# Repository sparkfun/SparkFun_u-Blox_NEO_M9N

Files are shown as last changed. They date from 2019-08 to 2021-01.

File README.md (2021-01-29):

SparkFun GPS NEO-M9N Breakout (Chip Antenna, U.FL, SMA) 
========================================

<table class="table table-hover table-striped table-bordered">
  <tr align="center">
   <td></td>
   <td></td>
    <td></td>
  </tr>
  <tr align="center">
    <td><a href="https://www.sparkfun.com/products/15733">SparkFun GPS NEO-M9N Chip Antenna <br />(GPS-15733)</a></td>
    <td><a href="https://www.sparkfun.com/products/15712">SparkFun GPS NEO-M9N U.FL <br />(GPS-15172)</a></td>
    <td><a href="https://www.sparkfun.com/products/17285">SparkFun GPS NEO-M9N SMA <br />(GPS-17285)</a></td>
  </tr>
</table>

The SparkFun NEO-M9N GPS Breakout is a high quality, GPS board with equally impressive configuration options. The NEO-M9N module is a 92-channel u-blox M9 engine GNSS receiver, meaning it can receive signals from the GPS, GLONASS, Galileo, and BeiDou constellations with ~1.5 meter accuracy. This breakout supports concurrent reception of four GNSS maximizes position accuracy in challenging conditions increasing precision and decreases lock time and thanks to the onboard rechargeable battery, you'll have backup power enabling the GPS to get a hot lock within seconds! Additionally, this u-blox receiver supports I<sup>2</sup>C (u-blox calls this Display Data Channel) which made it perfect for the Qwiic compatibility so we don't have to use up our precious UART ports. Utilizing our handy Qwiic system, no soldering is required to connect it to the rest of your system. However, we still have broken out 0.1"-spaced pins in case you prefer to use a breadboard. 

The NEO-M9N module detects jamming and spoofing events and can reports them to the host, so that the system can react to such events. A SAW (Surface Acoustic Wave) filter combined with an LNA (Low Noise Amplifier) in the RF path is integrated into the NEO-M9N module which allows normal operation even under strong RF interferences.

U-blox based GPS products are configurable using the popular, but dense, windows program called u-center. Plenty of different functions can be configured on the NEO-M9N: baud rates, update rates, geofencing, spoofing detection, external interrupts, SBAS/D-GPS, etc. All of this can be done within the SparkFun Arduino Library!

The SparkFun NEO-M9N GPS Breakout is also equipped with an on-board rechargeable battery that provides power to the RTC on the NEO-M9N.  This reduces the time-to-first fix from a cold start (~24s) to a hot start (~2s). The battery will maintain RTC and GNSS orbit data without being connected to power for plenty of time. 

Repository Contents
-------------------

* **/Documentation** - Data sheets for the NEO-M9N
* **/Hardware** - Eagle design files (.brd, .sch)
* **/Production** - Production panel files (.brd)

Documentation
--------------
* **[Library](https://github.com/sparkfun/SparkFun_u-blox_GNSS_Arduino_Library)** - Arduino Library the SparkFun GPS NEO-M9N.
* **[Qwiic UBlox GPS Py](https://github.com/sparkfun/Qwiic_Ublox_Gps_Py)** - Python Package
* **[Hookup Guide](https://learn.sparkfun.com/tutorials/sparkfun-gps-neo-m9n-hookup-guide)** - Basic hookup guide for the SparkFun GPS NEO-M9N

Product Versions
----------------
* [GPS-17285](https://www.sparkfun.com/products/17285) - GPS NEO-M9N SMA
* [GPS-15733](https://www.sparkfun.com/products/15733) - GPS NEO-M9N Chip Antenna
* [GPS-15712](https://www.sparkfun.com/products/15712) - GPS NEO-M9N u.FL

License Information
-------------------

This product is _**open source**_! 

Please review the LICENSE.md file for license information. 

If you have any questions or concerns on licensing, please contact technical support on our [SparkFun forums](https://forum.sparkfun.com/viewforum.php?f=152).

Distributed as-is; no warranty is given.

- Your friends at SparkFun.

_<COLLABORATION CREDIT>_

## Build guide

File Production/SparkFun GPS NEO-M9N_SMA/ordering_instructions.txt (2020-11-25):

panel size, 154x93mm
PCB thickness, 1.6mm
number of layers, 2
soldermask color, Red
silkscreen color, White
oz copper, 1oz
finish, HASL lead free
stencils, none
pcs per panel, 6
min trace width, 0.1524mm / 0.0060in
min drill size, 0.3048mm / 0.0120in

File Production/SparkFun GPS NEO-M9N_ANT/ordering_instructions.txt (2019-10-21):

panel size, 96x160mm
PCB thickness, 1.6mm
number of layers, 2
soldermask color, Red
silkscreen color, White
oz copper, 1oz
finish, HASL lead free
stencils, top+bottom
pcs per panel, 8
min trace width, 0.152400mm / 0.006000in
min drill size, 0.304800mm / 0.012000in

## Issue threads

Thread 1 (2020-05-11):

DFM issue with production PCB

szechyjs, 2020-05-11:
GTP is different than solder mask layer and the opening on the paste layer will cause the trace layer copper exposure.

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

edspark, 2020-05-11:
You're right about the classification of the layers but I think there's a little confusion on what they do. As you mentioned the GTP is "Gerber Top Paste" and is *not* the solder stop mask layer. Solder stop as you may know, stops the mask that covers and protects the copper. The solder stop mask layer in your image is the dark pink and the light-ish pink turned into green is the **top-paste**. It is usually the case that the paste fits inside the **solder stop** because solder only adheres to exposed copper (obviously). So, looking at the image linked in your comment, I can see that the **stop layer**, stops where the traces exits the pad. So no problem there.

The GTP in production is used entirely for the stencils that apply paste. What you're seeing is *not* exposed copper but "over-pasting". We use this technique on most of  the modules in our catalog that have castellated leads. If you've seen them then you know what I'm talking about. Just in case you haven't, those castellated leads have a lot of extra metal on them that suck up a lot of solder, and so we use this technique so that we get enough paste for good solder flow all the way up the lead.

In case you're not convinced, you can check the images we have on our [product page](https://www.sparkfun.com/products/16329), and see that the copper is *not* exposed at places where you might expect them to be. Or you can drag and drop the gerber files in this repository into this [3d Gerber Viewer](http://mayhewlabs.com/3dpcb) and get really up close to see what I'm talking about.

Closed 2020-05-11.

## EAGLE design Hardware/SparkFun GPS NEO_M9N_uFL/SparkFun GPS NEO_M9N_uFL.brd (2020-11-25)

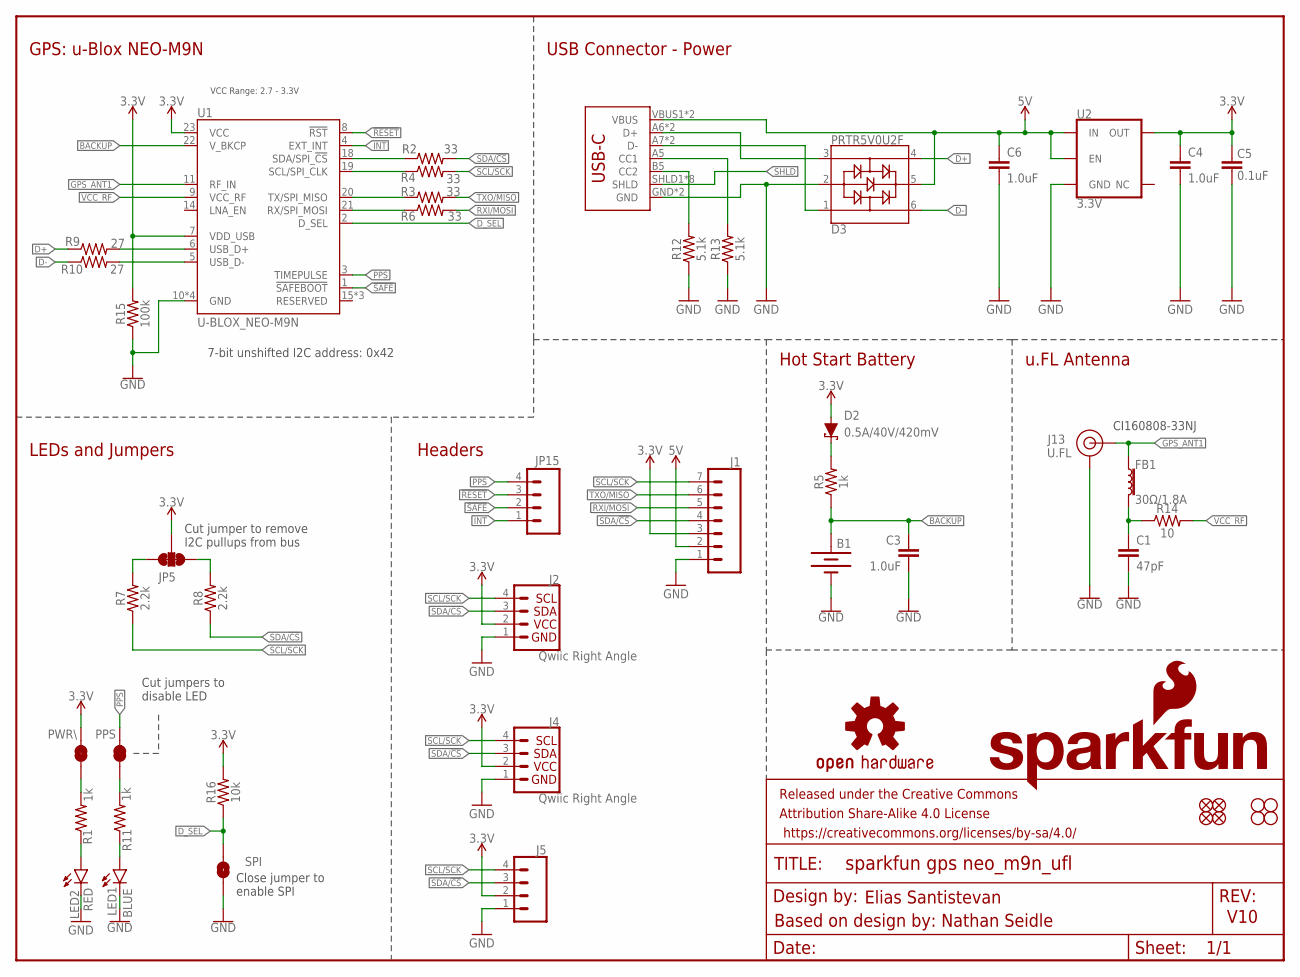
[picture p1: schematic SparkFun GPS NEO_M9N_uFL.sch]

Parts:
B1: 6.8MM_COIN_CELL; ML414H_IV01E
C1: 47pF; 0603
C3, C4, C6: 1.0uF; 0603
C5: 0.1uF; 0603
D2: 0.5A/40V/420mV; SOD-323
D3: PRTR5V0U2F; SOT886
FB1: 30Ω/1.8A; 0603
FRAME1: FRAME-LETTER; CREATIVE_COMMONS
J1: CONN_07NO_SILK; 1X07_NO_SILK
J2, J4: Qwiic Right Angle; JST04_1MM_RA
J3: USB_C2-LAYER; USB-C-16P
J5: CONN_041X04_NO_SILK; 1X04_NO_SILK
J13: U.FL
JP5: JUMPER-SMT_3_2-NC_TRACE_SILK; SMT-JUMPER_3_2-NC_TRACE_SILK
JP15: CONN_041X04_NO_SILK; 1X04_NO_SILK
JP21, JP61, JP71, JP81: FIDUCIALUFIDUCIAL; MICRO-FIDUCIAL
JP31, JP41, JP91, JP101: STAND-OFF
LED1: BLUE; LED-0603
LED2: RED; LED-0603
LOGO1: OSHW-LOGOMINI; OSHW-LOGO-MINI
LOGO2: SFE_LOGO_NAME_FLAME.1_INCH; SFE_LOGO_NAME_FLAME_.1
PPS: JUMPER-SMT_2_NC_TRACE_SILK; SMT-JUMPER_2_NC_TRACE_SILK
PWR\: JUMPER-SMT_2_NC_TRACE_SILK; SMT-JUMPER_2_NC_TRACE_SILK
R1, R5, R11: 1k; 0603
R2, R3, R4, R6: 33; 0603
R7, R8: 2.2k; 0603
R9, R10: 27; 0603
R12, R13: 5.1k; 0603
R14: 10; 0603
R15: 100k; 0603
R16: 10k; 0402
SPI: JUMPER-SMT_2_NO_SILK; SMT-JUMPER_2_NO_SILK
U1: U-BLOX_NEO-M9N; NEO-M9N
U2: 3.3V; SOT23-5

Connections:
3.3V: C4.1, C5.2, D2.A, J1.3, J2.2, J4.2, J5.2, JP5.2, PWR\.2, R15.2, R16.2, U1.7 (VDD_USB), U1.23 (VCC), U2.5 (OUT)
5V: C6.1, D3.5, J1.2, J3.VBUS1 (VBUS), J3.VBUS2 (VBUS), U2.1 (IN), U2.3 (EN)
!RESET: JP15.3, U1.8 (!RST)
!SAFE: JP15.2, U1.1 (!SAFEBOOT!)
ANT_VCC: C1.1, FB1.2, R14.1
BACKUP: B1.+, C3.1, R5.1, U1.22 (V_BKCP)
D+: D3.4, R9.1
D-: D3.6, R10.1
D_SEL: R16.1, SPI.2, U1.2 (D_SEL)
GND: B1.-, C1.2, C3.2, C4.2, C5.1, C6.2, D3.2, J1.1, J2.1, J3.GND, J3.GND2 (GND), J4.1, J5.1, J13.1 (GND), J13.2 (GND), LED1.C, LED2.C, R12.1, R13.1, R15.1, SPI.1, U1.10 (GND), U1.12 (GND), U1.13 (GND), U1.24 (GND), U2.2 (GND)
GPS_ANT1: FB1.1, J13.FEED (SIGNAL), U1.11 (RF_IN)
INT: JP15.1, U1.4 (EXT_INT)
unnamed: PWR\.1, R1.2
unnamed: LED1.A, R11.1
unnamed: PPS.1, R11.2
unnamed: JP5.1, R8.2
unnamed: D2.C, R5.2
unnamed: J3.B5 (CC2), R12.2
unnamed: JP5.3, R7.2
unnamed: J3.A5 (CC1), R13.2
unnamed: LED2.A, R1.1
unnamed: R9.2, U1.6 (USB_D+)
unnamed: R10.2, U1.5 (USB_D-)
PPS: JP15.4, PPS.2, U1.3 (TIMEPULSE)
RXI/MOSI: J1.5, R6.2
RXLV: R6.1, U1.21 (RX/SPI_MOSI)
SCL/SCK: J1.7, J2.4, J4.4, J5.4, R4.2, R7.1
SCL_LV: R4.1, U1.19 (SCL/SPI_CLK)
SDA/!CS: J1.4, J2.3, J4.3, J5.3, R2.2, R8.1
SDA_LV: R2.1, U1.18 (SDA/SPI_!CS!)
SHLD: J3.SHLD1 (SHLD), J3.SHLD2 (SHLD), J3.SHLD3 (SHLD), J3.SHLD4 (SHLD), J3.SHLD5 (SHLD), J3.SHLD6 (SHLD), J3.SHLD7 (SHLD), J3.SHLD8 (SHLD)
TXLV: R3.1, U1.20 (TX/SPI_MISO)
TXO/MISO: J1.6, R3.2
USB_D+: D3.3, J3.A6 (D+), J3.B6 (D+)
USB_D-: D3.1, J3.A7 (D-), J3.B7 (D-)
VCC_RF: R14.2, U1.9 (VCC_RF)

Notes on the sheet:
V10
7-bit unshifted I2C address: 0x42
Cut jumper to remove I2C pullups from bus
Cut jumpers to disable LED
Close jumper to enable SPI
CI160808-33NJ
Elias Santistevan
Headers
LEDs and Jumpers
Hot Start Battery
GPS: u-Blox NEO-M9N
u.FL Antenna
USB Connector - Power
Based on design by: Nathan Seidle
VCC Range: 2.7 - 3.3V

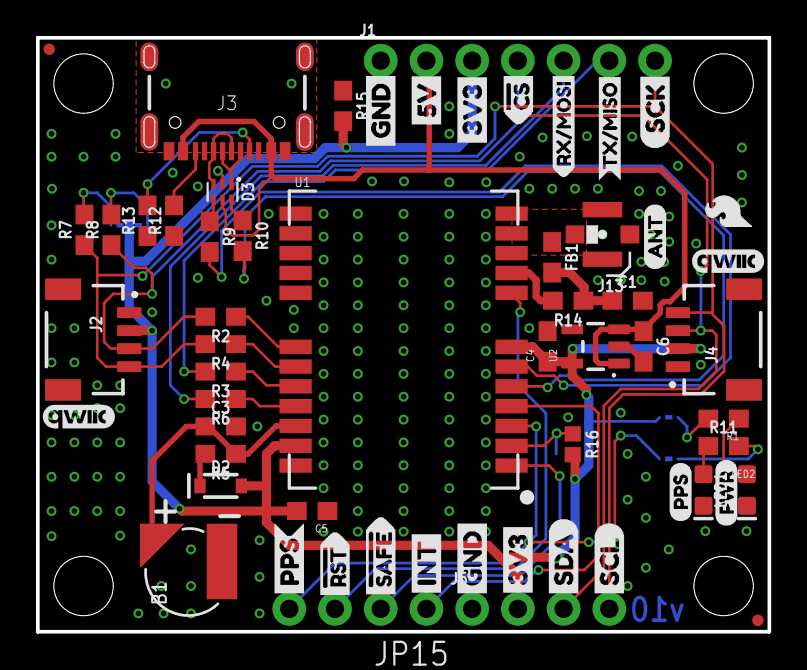
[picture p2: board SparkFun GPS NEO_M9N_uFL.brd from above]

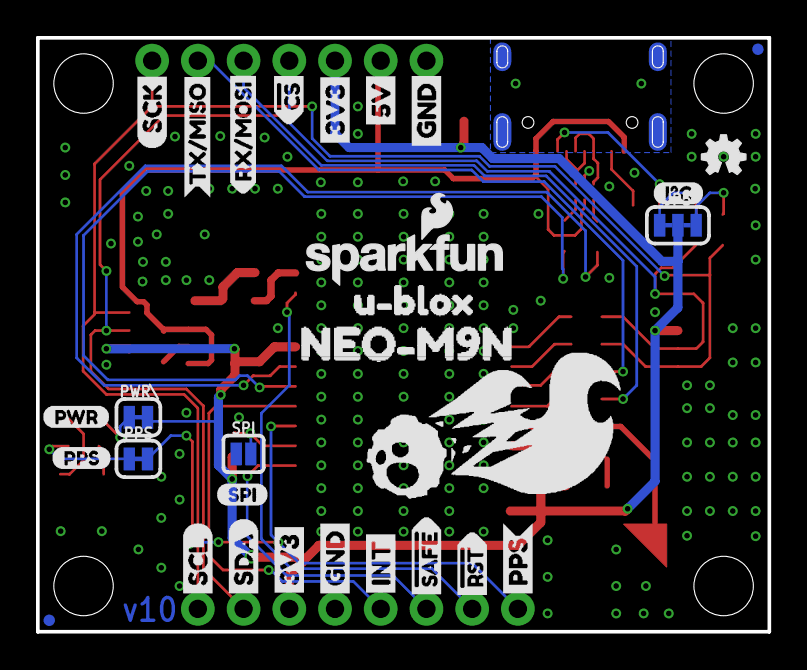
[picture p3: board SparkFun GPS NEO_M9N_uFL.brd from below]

Board: 2 copper layers, 40.6 x 33.0 mm, 94 parts (30 on the bottom side), 36 nets.

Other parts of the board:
U$1, U$4: SDA-[)
U$2: NEO#M9N1
U$3, U$5: SCL-[)
U$6, U$7, U$60, U$61: 3V3-04
U$8, U$9, U$62, U$63: GND-04
U$10: I_SUPER2_C-()-03
U$11: SPI1
U$12, U$52: PPS0
U$13, U$14: QWIIC_4MM
U$15, U$16: INT8
U$17: PWR1
U$18: PWR-()-03
U$19, U$20: 5V
U$21: NEO_GPS_BOARD_SILK_FINAL#03#JPG
U$22: U#BLOX3
U$23, U$24: CS#-<]
U$25: ANT0
U$26: RX#MOSI2
U$31: RX#MOSI3
U$33: SFE_LOGO_FLAME_.1
U$34: TX#MISO0
U$35, U$36: #RST3
U$37: TX#MISO1
U$38, U$41: SCK-(]-04
U$39, U$40: #SAFE1
U$43, U$44: PPS5

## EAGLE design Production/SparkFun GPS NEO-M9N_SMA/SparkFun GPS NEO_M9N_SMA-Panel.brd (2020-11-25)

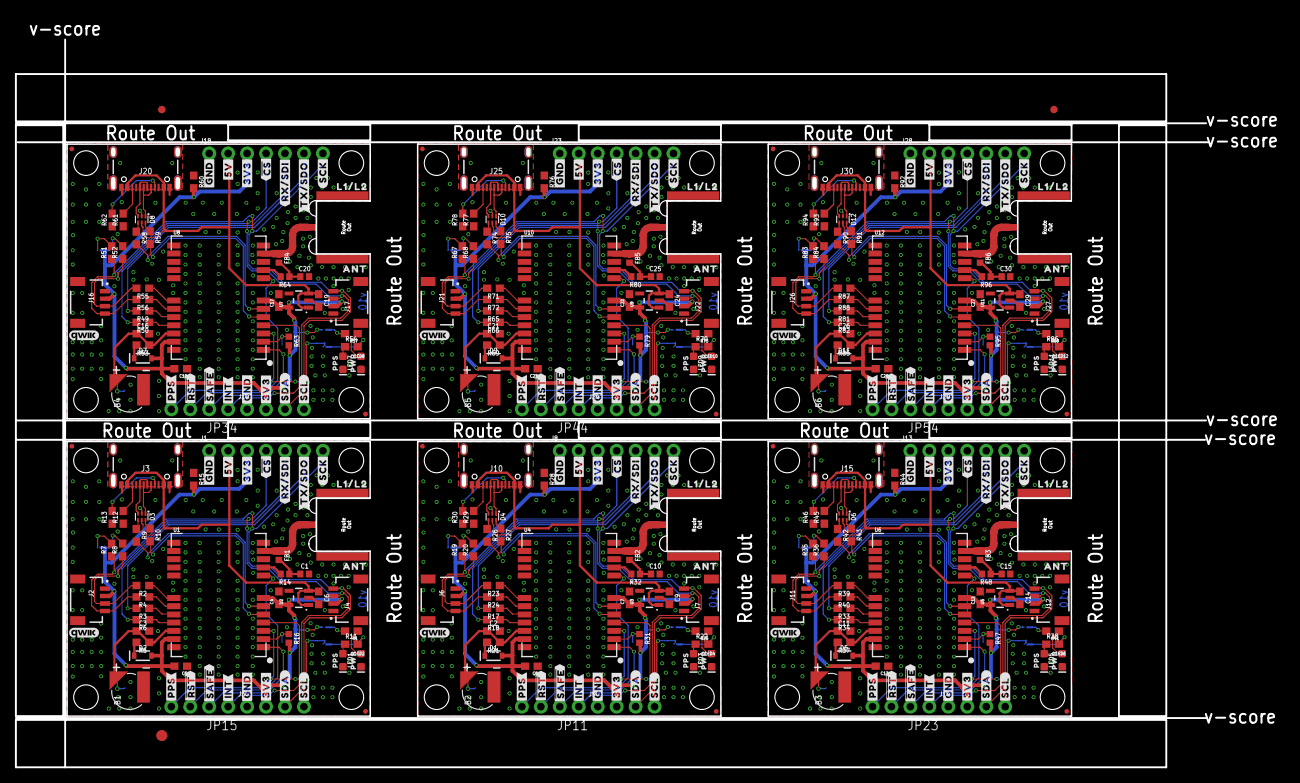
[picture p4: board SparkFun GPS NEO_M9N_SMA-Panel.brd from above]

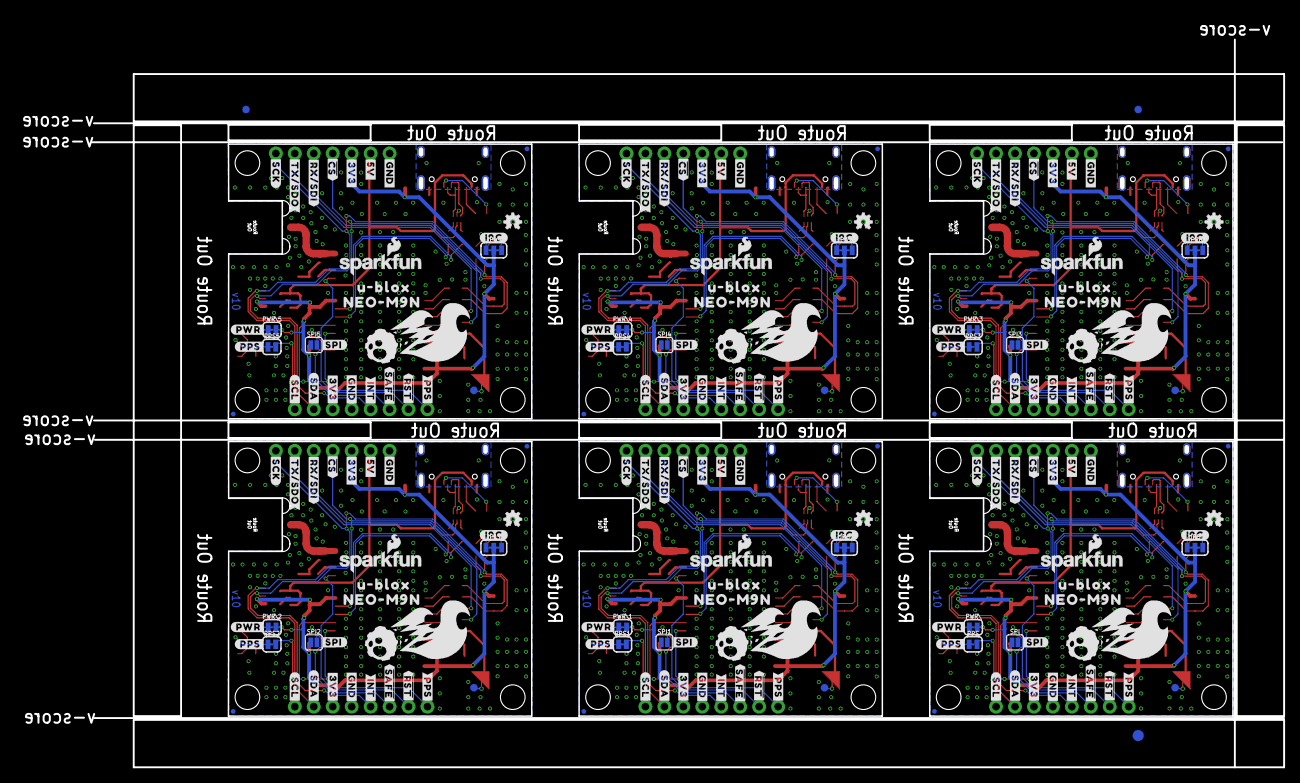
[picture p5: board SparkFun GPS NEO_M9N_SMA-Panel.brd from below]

Board: 2 copper layers, 159.8 x 97.5 mm, 564 parts (189 on the bottom side), 216 nets.

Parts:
B1, B2, B3, B4, B5, B6: 6.8MM_COIN_CELL; ML414H_IV01E
C1, C10, C15, C20, C25, C30: 47pF; 0402
C2, C3, C4, C6, C7, C9, C11, C12, C14, C16, C17, C19, C21, C22, C24, C26, C27, C29: 1.0uF; 0603
C5, C8, C13, C18, C23, C28: 0.1uF; 0603
D1, D2, D5, D7, D9, D11: 0.5A/40V/420mV; SOD-323
D3, D4, D6, D8, D10, D12: PRTR5V0U2F; SOT886
E1, E2, E3, E4, E5, E6: ANTENNA-GROUNDEDEDGE_SMA_SMD; SMA-EDGE-SMD
E$1, E$2, E$3, E$4: FIDUCIAL-1X2
E$5, E$6: FIDUCIAL-1.5X3
FB1, FB2, FB3, FB4, FB5, FB6: FERRITE_BEAD-120_OHM-0402; 0402
J1, J8, J13, J18, J23, J28: 1X07_NO_SILK
J2, J4, J6, J7, J11, J12, J16, J17, J21, J22, J26, J27: Qwiic Right Angle; JST04_1MM_RA
J3, J10, J15, J20, J25, J30: USB-C-16P-2LAYER-PADS
J5, J9, J14, J19, J24, J29: 1X04_NO_SILK
JP1, JP2, JP9, JP10, JP12, JP13, JP20, JP22, JP24, JP25, JP31, JP32, JP33, JP35, JP36, JP42, JP43, JP45, JP46, JP52, JP53, JP55, JP91, JP101: STAND-OFF
JP3, JP4, JP7, JP8, JP14, JP16, JP18, JP19, JP21, JP26, JP27, JP29, JP30, JP37, JP38, JP40, JP41, JP47, JP48, JP50, JP51, JP61, JP71, JP81: FIDUCIALUFIDUCIAL; MICRO-FIDUCIAL
JP5, JP6, JP17, JP28, JP39, JP49: JUMPER-SMT_3_2-NC_TRACE_SILK; SMT-JUMPER_3_2-NC_TRACE_SILK
JP11, JP15, JP23, JP34, JP44, JP54: 1X04_NO_SILK
LED1, LED3, LED5, LED7, LED9, LED11: BLUE; LED-0603
LED2, LED4, LED6, LED8, LED10, LED12: RED; LED-0603
LOGO1, LOGO3, LOGO5, LOGO7, LOGO9, LOGO11: OSHW-LOGOMINI; OSHW-LOGO-MINI
LOGO2, LOGO4, LOGO6, LOGO8, LOGO10, LOGO12: SFE_LOGO_NAME_FLAME.1_INCH; SFE_LOGO_NAME_FLAME_.1
PPS, PPS1, PPS2, PPS3, PPS4, PPS5: JUMPER-SMT_2_NC_TRACE_SILK; SMT-JUMPER_2_NC_TRACE_SILK
PWR\, PWR\1, PWR\2, PWR\3, PWR\4, PWR\5: JUMPER-SMT_2_NC_TRACE_SILK; SMT-JUMPER_2_NC_TRACE_SILK
R1, R5, R11, R21, R22, R25, R37, R38, R41, R53, R54, R57, R69, R70, R73, R85, R86, R89: 1k; 0603
R2, R3, R4, R6, R17, R18, R23, R24, R33, R34, R39, R40, R49, R50, R55, R56, R65, R66, R71, R72, R81, R82, R87, R88: 33; 0603
R7, R8, R19, R20, R35, R36, R51, R52, R67, R68, R83, R84: 2.2k; 0603
R9, R10, R26, R27, R42, R43, R58, R59, R74, R75, R90, R91: 27; 0603
R12, R13, R29, R30, R45, R46, R61, R62, R77, R78, R93, R94: 5.1k; 0603
R14, R32, R48, R64, R80, R96: 33; 0402
R15, R28, R44, R60, R76, R92: 100k; 0603
R16, R31, R47, R63, R79, R95: 10k; 0402
SPI, SPI1, SPI2, SPI3, SPI4, SPI5: JUMPER-SMT_2_NO_SILK; SMT-JUMPER_2_NO_SILK
TP1, TP2, TP3, TP4, TP5, TP6: TEST-POINT3X4; PAD.03X.04
U1, U4, U6, U8, U10, U12: U-BLOX_NEO-M9N; NEO-M9N/M8T/M8U
U2, U3, U5, U7, U9, U11: 3.3V; SOT23-5
U$1, U$45, U$87, U$129, U$171, U$213: ##CS##9
U$2, U$62, U$104, U$146, U$188, U$230: U#BLOX19
U$3, U$46, U$88, U$130, U$172, U$214: ##SAFE##15
U$4, U$5, U$39, U$40, U$47, U$48, U$78, U$79, U$89, U$90, U$120, U$121, U$131, U$132, U$162, U$163, U$173, U$174, U$204, U$205, U$215, U$216, U$246, U$247: #3V3#6
U$6, U$42, U$49, U$81, U$91, U$123, U$133, U$165, U$175, U$207, U$217, U$249: #5V#1
U$7, U$8, U$38, U$41, U$50, U$51, U$77, U$80, U$92, U$93, U$119, U$122, U$134, U$135, U$161, U$164, U$176, U$177, U$203, U$206, U$218, U$219, U$245, U$248: #GND#0
U$9, U$52, U$94, U$136, U$178, U$220: #INT#16
U$10, U$83, U$125, U$167, U$209, U$251: PPS7
U$11, U$32, U$53, U$71, U$95, U$113, U$137, U$155, U$179, U$197, U$221, U$239: #PPS#13
U$12, U$63, U$105, U$147, U$189, U$231: #SPI#22
U$13, U$84, U$126, U$168, U$210, U$252: PWR6
U$14, U$43, U$85, U$127, U$169, U$211: QWIIC_4MM
U$15, U$54, U$96, U$138, U$180, U$222: #RX#SDI#10
U$16, U$55, U$97, U$139, U$181, U$223: #SCK#12
U$17, U$72, U$114, U$156, U$198, U$240: #PWR#1
U$18, U$56, U$98, U$140, U$182, U$224: #SCL#18
U$19, U$57, U$99, U$141, U$183, U$225: #SDA#17
U$20, U$58, U$100, U$142, U$184, U$226: #TX#SDO#11
U$21, U$44, U$86, U$128, U$170, U$212: NEO_GPS_BOARD_SILK_FINAL#03#JPG
U$22, U$67, U$109, U$151, U$193, U$235: ##SAFE##11
U$23, U$59, U$101, U$143, U$185, U$227: L1#L28
U$24, U$60, U$102, U$144, U$186, U$228: ANT8
U$25, U$61, U$103, U$145, U$187, U$229: NEO#M9N20
U$26, U$64, U$106, U$148, U$190, U$232: ##CS##6
U$27, U$65, U$107, U$149, U$191, U$233: ##RST##12
U$28, U$66, U$108, U$150, U$192, U$234: ##RST##2
U$29, U$68, U$110, U$152, U$194, U$236: #I2C#3
U$30, U$69, U$111, U$153, U$195, U$237: #INT#10
U$31, U$70, U$112, U$154, U$196, U$238: #PPS#0
U$33, U$73, U$115, U$157, U$199, U$241: #RX#SDI#4
U$34, U$74, U$116, U$158, U$200, U$242: #SCK#3
U$35, U$75, U$117, U$159, U$201, U$243: #SCL#8
U$36, U$76, U$118, U$160, U$202, U$244: #SDA#9
U$37, U$82, U$124, U$166, U$208, U$250: #TX#SDO#5

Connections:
3.3V: C4.1, C5.2, D2.A, J1.3, J2.2, J4.2, J5.2, JP5.2, PWR\.2, R15.2, R16.2, U1.7, U1.23, U2.5
3.3V1: C7.1, C8.2, D1.A, J6.2, J7.2, J8.3, J9.2, JP6.2, PWR\1.2, R28.2, R31.2, U3.5, U4.7, U4.23
3.3V2: C12.1, C13.2, D5.A, J11.2, J12.2, J13.3, J14.2, JP17.2, PWR\2.2, R44.2, R47.2, U5.5, U6.7, U6.23
3.3V3: C17.1, C18.2, D7.A, J16.2, J17.2, J18.3, J19.2, JP28.2, PWR\3.2, R60.2, R63.2, U7.5, U8.7, U8.23
3.3V4: C22.1, C23.2, D9.A, J21.2, J22.2, J23.3, J24.2, JP39.2, PWR\4.2, R76.2, R79.2, U9.5, U10.7, U10.23
3.3V5: C27.1, C28.2, D11.A, J26.2, J27.2, J28.3, J29.2, JP49.2, PWR\5.2, R92.2, R95.2, U11.5, U12.7, U12.23
5V: C6.1, D3.5, J1.2, J3.VBUS1, J3.VBUS2, U2.1, U2.3
5V1: C9.1, D4.5, J8.2, J10.VBUS1, J10.VBUS2, U3.1, U3.3
5V2: C14.1, D6.5, J13.2, J15.VBUS1, J15.VBUS2, U5.1, U5.3
5V3: C19.1, D8.5, J18.2, J20.VBUS1, J20.VBUS2, U7.1, U7.3
5V4: C24.1, D10.5, J23.2, J25.VBUS1, J25.VBUS2, U9.1, U9.3
5V5: C29.1, D12.5, J28.2, J30.VBUS1, J30.VBUS2, U11.1, U11.3
!RESET: JP15.3, U1.8
!RESET1: JP11.3, U4.8
!RESET2: JP23.3, U6.8
!RESET3: JP34.3, U8.8
!RESET4: JP44.3, U10.8
!RESET5: JP54.3, U12.8
!SAFE: JP15.2, U1.1
!SAFE1: JP11.2, U4.1
!SAFE2: JP23.2, U6.1
!SAFE3: JP34.2, U8.1
!SAFE4: JP44.2, U10.1
!SAFE5: JP54.2, U12.1
D+: D3.4, R9.1
D+1: D4.4, R26.1
D+2: D6.4, R42.1
D+3: D8.4, R58.1
D+4: D10.4, R74.1
D+5: D12.4, R90.1
D-: D3.6, R10.1
D-1: D4.6, R27.1
D-2: D6.6, R43.1
D-3: D8.6, R59.1
D-4: D10.6, R75.1
D-5: D12.6, R91.1
D_SEL: R16.1, SPI.2, U1.2
D_SEL1: R31.1, SPI1.2, U4.2
D_SEL2: R47.1, SPI2.2, U6.2
D_SEL3: R63.1, SPI3.2, U8.2
D_SEL4: R79.1, SPI4.2, U10.2
D_SEL5: R95.1, SPI5.2, U12.2
GND: B1.-, C1.2, C3.2, C4.2, C5.1, C6.2, D3.2, E1.GND@0, E1.GND@1, J1.1, J2.1, J3.GND, J3.GND2, J4.1, J5.1, LED1.C, LED2.C, R12.1, R13.1, R15.1, SPI.1, U1.10, U1.12, U1.13, U1.24, U2.2
GND1: B2.-, C2.2, C7.2, C8.1, C9.2, C10.2, D4.2, E2.GND@0, E2.GND@1, J6.1, J7.1, J8.1, J9.1, J10.GND, J10.GND2, LED3.C, LED4.C, R28.1, R29.1, R30.1, SPI1.1, U3.2, U4.10, U4.12, U4.13, U4.24
GND2: B3.-, C11.2, C12.2, C13.1, C14.2, C15.2, D6.2, E3.GND@0, E3.GND@1, J11.1, J12.1, J13.1, J14.1, J15.GND, J15.GND2, LED5.C, LED6.C, R44.1, R45.1, R46.1, SPI2.1, U5.2, U6.10, U6.12, U6.13, U6.24
GND3: B4.-, C16.2, C17.2, C18.1, C19.2, C20.2, D8.2, E4.GND@0, E4.GND@1, J16.1, J17.1, J18.1, J19.1, J20.GND, J20.GND2, LED7.C, LED8.C, R60.1, R61.1, R62.1, SPI3.1, U7.2, U8.10, U8.12, U8.13, U8.24
GND4: B5.-, C21.2, C22.2, C23.1, C24.2, C25.2, D10.2, E5.GND@0, E5.GND@1, J21.1, J22.1, J23.1, J24.1, J25.GND, J25.GND2, LED9.C, LED10.C, R76.1, R77.1, R78.1, SPI4.1, U9.2, U10.10, U10.12, U10.13, U10.24
GND5: B6.-, C26.2, C27.2, C28.1, C29.2, C30.2, D12.2, E6.GND@0, E6.GND@1, J26.1, J27.1, J28.1, J29.1, J30.GND, J30.GND2, LED11.C, LED12.C, R92.1, R93.1, R94.1, SPI5.1, U11.2, U12.10, U12.12, U12.13, U12.24
GPS_ANT1: E1.SIG, FB1.1, U1.11
GPS_ANT2: E2.SIG, FB2.1, U4.11
GPS_ANT3: E3.SIG, FB3.1, U6.11
GPS_ANT4: E4.SIG, FB4.1, U8.11
GPS_ANT5: E5.SIG, FB5.1, U10.11
GPS_ANT6: E6.SIG, FB6.1, U12.11
INT: JP15.1, U1.4
INT1: JP11.1, U4.4
INT2: JP23.1, U6.4
INT3: JP34.1, U8.4
INT4: JP44.1, U10.4
INT5: JP54.1, U12.4
unnamed: PWR\.1, R1.2
unnamed: LED1.A, R11.1
unnamed: C1.1, FB1.2, R14.1
unnamed: PPS.1, R11.2
unnamed: JP5.1, R8.2
unnamed: D2.C, R5.2
unnamed: J3.B5, R12.2
unnamed: JP5.3, R7.2
unnamed: J3.A5, R13.2
unnamed: LED2.A, R1.1
unnamed: R9.2, U1.6
unnamed: R10.2, U1.5
unnamed: JP6.1, R20.2
unnamed: JP6.3, R19.2
unnamed: LED3.A, R22.1
unnamed: PPS1.1, R22.2
unnamed: D1.C, R21.2
unnamed: LED4.A, R25.1
unnamed: R26.2, U4.6
unnamed: R27.2, U4.5
unnamed: PWR\1.1, R25.2
unnamed: J10.B5, R29.2
unnamed: J10.A5, R30.2
unnamed: C10.1, FB2.2, R32.1
unnamed: JP17.1, R36.2
unnamed: JP17.3, R35.2
unnamed: LED5.A, R38.1
unnamed: PPS2.1, R38.2
unnamed: D5.C, R37.2
unnamed: LED6.A, R41.1
unnamed: R42.2, U6.6
unnamed: R43.2, U6.5
unnamed: PWR\2.1, R41.2
unnamed: J15.B5, R45.2
unnamed: J15.A5, R46.2
unnamed: C15.1, FB3.2, R48.1
unnamed: JP28.1, R52.2
unnamed: JP28.3, R51.2
unnamed: LED7.A, R54.1
unnamed: PPS3.1, R54.2
unnamed: D7.C, R53.2
unnamed: LED8.A, R57.1
unnamed: R58.2, U8.6
unnamed: R59.2, U8.5
unnamed: PWR\3.1, R57.2
unnamed: J20.B5, R61.2
unnamed: J20.A5, R62.2
unnamed: C20.1, FB4.2, R64.1
unnamed: JP39.1, R68.2
unnamed: JP39.3, R67.2
unnamed: LED9.A, R70.1
unnamed: PPS4.1, R70.2
unnamed: D9.C, R69.2
unnamed: LED10.A, R73.1
unnamed: R74.2, U10.6
unnamed: R75.2, U10.5
unnamed: PWR\4.1, R73.2
unnamed: J25.B5, R77.2
unnamed: J25.A5, R78.2
unnamed: C25.1, FB5.2, R80.1
unnamed: JP49.1, R84.2
unnamed: JP49.3, R83.2
unnamed: LED11.A, R86.1
unnamed: PPS5.1, R86.2
unnamed: D11.C, R85.2
unnamed: LED12.A, R89.1
unnamed: R90.2, U12.6
unnamed: R91.2, U12.5
unnamed: PWR\5.1, R89.2
unnamed: J30.B5, R93.2
unnamed: J30.A5, R94.2
unnamed: C30.1, FB6.2, R96.1
PPS: JP15.4, PPS.2, U1.3
PPS1: JP11.4, PPS1.2, U4.3
PPS2: JP23.4, PPS2.2, U6.3
PPS3: JP34.4, PPS3.2, U8.3
PPS4: JP44.4, PPS4.2, U10.3
PPS5: JP54.4, PPS5.2, U12.3
RXI/SDI: J1.5, R6.2
RXI/SDI1: J8.5, R18.2
RXI/SDI2: J13.5, R34.2
RXI/SDI3: J18.5, R50.2
RXI/SDI4: J23.5, R66.2
RXI/SDI5: J28.5, R82.2
RXLV: R6.1, U1.21
RXLV1: R18.1, U4.21
RXLV2: R34.1, U6.21
RXLV3: R50.1, U8.21
RXLV4: R66.1, U10.21
RXLV5: R82.1, U12.21
SCL/SCK: J1.7, J2.4, J4.4, J5.4, R4.2, R7.1
SCL/SCK1: J6.4, J7.4, J8.7, J9.4, R19.1, R24.2
SCL/SCK2: J11.4, J12.4, J13.7, J14.4, R35.1, R40.2
SCL/SCK3: J16.4, J17.4, J18.7, J19.4, R51.1, R56.2
SCL/SCK4: J21.4, J22.4, J23.7, J24.4, R67.1, R72.2
SCL/SCK5: J26.4, J27.4, J28.7, J29.4, R83.1, R88.2
SCL_LV: R4.1, U1.19
SCL_LV1: R24.1, U4.19
SCL_LV2: R40.1, U6.19
SCL_LV3: R56.1, U8.19
SCL_LV4: R72.1, U10.19
SCL_LV5: R88.1, U12.19
SDA/!CS: J1.4, J2.3, J4.3, J5.3, R2.2, R8.1
SDA/!CS1: J6.3, J7.3, J8.4, J9.3, R20.1, R23.2
SDA/!CS2: J11.3, J12.3, J13.4, J14.3, R36.1, R39.2
SDA/!CS3: J16.3, J17.3, J18.4, J19.3, R52.1, R55.2
SDA/!CS4: J21.3, J22.3, J23.4, J24.3, R68.1, R71.2
SDA/!CS5: J26.3, J27.3, J28.4, J29.3, R84.1, R87.2
SDA_LV: R2.1, U1.18
SDA_LV1: R23.1, U4.18
SDA_LV2: R39.1, U6.18
SDA_LV3: R55.1, U8.18
SDA_LV4: R71.1, U10.18
SDA_LV5: R87.1, U12.18
SHLD: J3.SHLD1, J3.SHLD2, J3.SHLD3, J3.SHLD4
SHLD1: J10.SHLD1, J10.SHLD2, J10.SHLD3, J10.SHLD4
SHLD2: J15.SHLD1, J15.SHLD2, J15.SHLD3, J15.SHLD4
SHLD3: J20.SHLD1, J20.SHLD2, J20.SHLD3, J20.SHLD4
SHLD4: J25.SHLD1, J25.SHLD2, J25.SHLD3, J25.SHLD4
SHLD5: J30.SHLD1, J30.SHLD2, J30.SHLD3, J30.SHLD4
TXLV: R3.1, U1.20
TXLV1: R17.1, U4.20
TXLV2: R33.1, U6.20
TXLV3: R49.1, U8.20
TXLV4: R65.1, U10.20
TXLV5: R81.1, U12.20
TXO/SDO: J1.6, R3.2
TXO/SDO1: J8.6, R17.2
TXO/SDO2: J13.6, R33.2
TXO/SDO3: J18.6, R49.2
TXO/SDO4: J23.6, R65.2
TXO/SDO5: J28.6, R81.2
USB_D+: D3.3, J3.A6, J3.B6
USB_D+1: D4.3, J10.A6, J10.B6
USB_D+2: D6.3, J15.A6, J15.B6
USB_D+3: D8.3, J20.A6, J20.B6
USB_D+4: D10.3, J25.A6, J25.B6
USB_D+5: D12.3, J30.A6, J30.B6
USB_D-: D3.1, J3.A7, J3.B7
USB_D-1: D4.1, J10.A7, J10.B7
USB_D-2: D6.1, J15.A7, J15.B7
USB_D-3: D8.1, J20.A7, J20.B7
USB_D-4: D10.1, J25.A7, J25.B7
USB_D-5: D12.1, J30.A7, J30.B7
VCC_RF: R14.2, U1.9
VCC_RF1: R32.2, U4.9
VCC_RF2: R48.2, U6.9
VCC_RF3: R64.2, U8.9
VCC_RF4: R80.2, U10.9
VCC_RF5: R96.2, U12.9
V_BATT: B1.+, C3.1, R5.1, TP1.P$1, U1.22
V_BATT1: B2.+, C2.1, R21.1, TP2.P$1, U4.22
V_BATT2: B3.+, C11.1, R37.1, TP3.P$1, U6.22
V_BATT3: B4.+, C16.1, R53.1, TP4.P$1, U8.22
V_BATT4: B5.+, C21.1, R69.1, TP5.P$1, U10.22
V_BATT5: B6.+, C26.1, R85.1, TP6.P$1, U12.22

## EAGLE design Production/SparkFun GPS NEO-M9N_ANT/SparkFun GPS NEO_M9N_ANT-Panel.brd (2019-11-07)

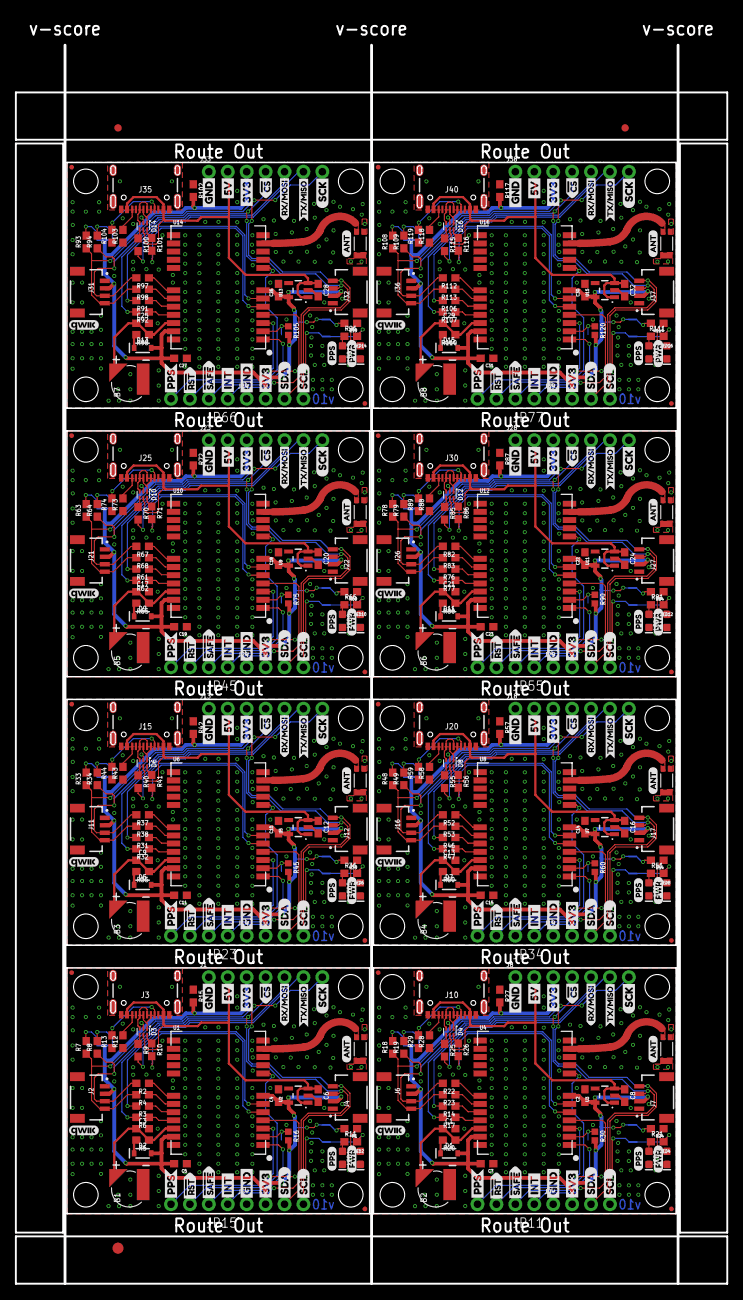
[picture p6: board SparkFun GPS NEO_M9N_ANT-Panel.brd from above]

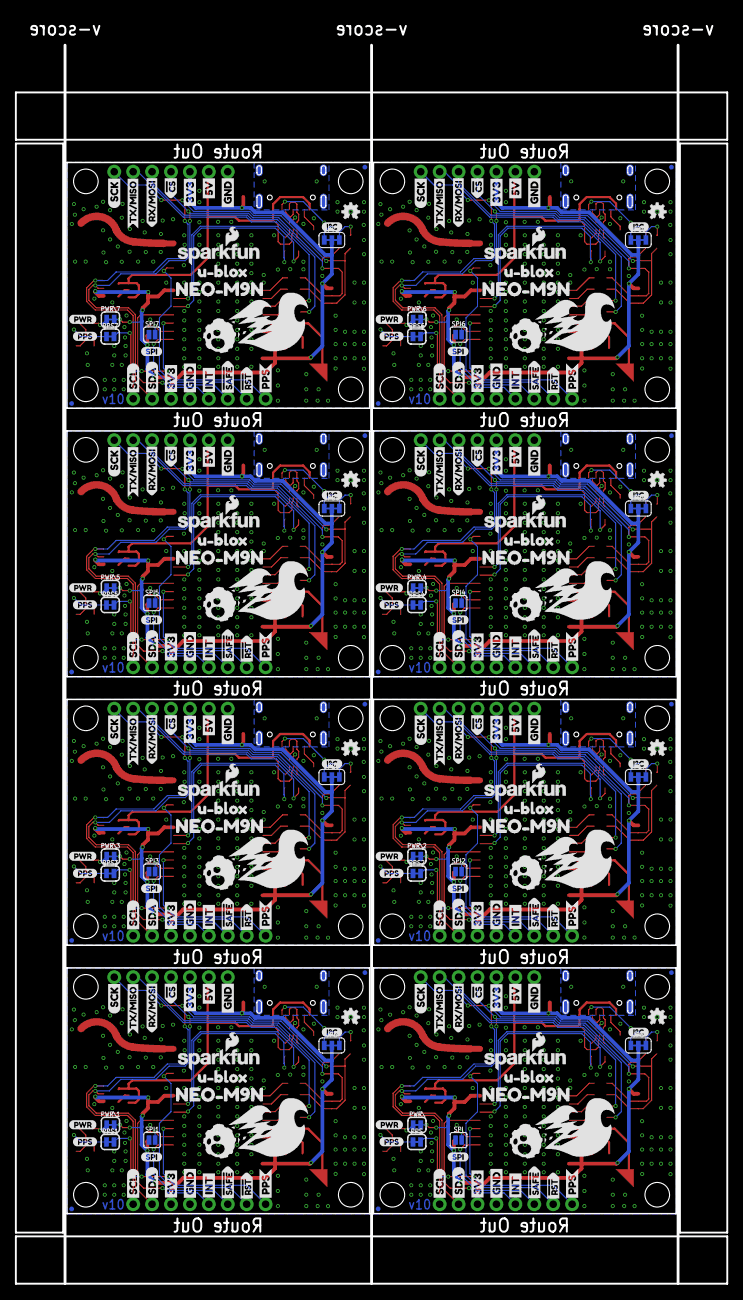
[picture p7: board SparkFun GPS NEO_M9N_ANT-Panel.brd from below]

Board: 2 copper layers, 95.5 x 166.3 mm, 707 parts (240 on the bottom side), 272 nets.

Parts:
B1, B2, B3, B4, B5, B6, B7, B8: 6.8MM_COIN_CELL; ML414H_IV01E
C1, C2, C3, C4, C6, C8, C9, C10, C12, C13, C14, C16, C17, C18, C20, C21, C22, C24, C25, C26, C28, C29, C30, C32: 1.0uF; 0603
C5, C7, C11, C15, C19, C23, C27, C31: 0.1uF; 0603
D1, D2, D5, D7, D9, D11, D13, D15: 0.5A/40V/420mV; SOD-323
D3, D4, D6, D8, D10, D12, D14, D16: PRTR5V0U2F; SOT886
E$1, E$2: FIDUCIAL-1X2
E$3: FIDUCIAL-1.5X3
J1, J8, J13, J18, J23, J28, J33, J38: 1X07_NO_SILK
J2, J4, J6, J7, J11, J12, J16, J17, J21, J22, J26, J27, J31, J32, J36, J37: Qwiic Right Angle; JST04_1MM_RA
J3, J10, J15, J20, J25, J30, J35, J40: USB-C-16P
J5, J9, J14, J19, J24, J29, J34, J39: 1X04_NO_SILK
JP1, JP2, JP9, JP10, JP12, JP13, JP20, JP22, JP24, JP25, JP31, JP32, JP33, JP35, JP36, JP41, JP43, JP44, JP46, JP47, JP53, JP54, JP56, JP57, JP64, JP65, JP67, JP68, JP75, JP76, JP91, JP101: STAND-OFF
JP3, JP4, JP7, JP8, JP14, JP16, JP18, JP19, JP21, JP26, JP27, JP29, JP30, JP37, JP38, JP40, JP42, JP48, JP49, JP51, JP52, JP58, JP59, JP61, JP62, JP63, JP69, JP70, JP71, JP73, JP74, JP81: FIDUCIALUFIDUCIAL; MICRO-FIDUCIAL
JP5, JP6, JP17, JP28, JP39, JP50, JP60, JP72: JUMPER-SMT_3_2-NC_TRACE_SILK; SMT-JUMPER_3_2-NC_TRACE_SILK
JP11, JP15, JP23, JP34, JP45, JP55, JP66, JP77: 1X04_NO_SILK
LED1, LED3, LED5, LED7, LED9, LED11, LED13, LED15: BLUE; LED-0603
LED2, LED4, LED6, LED8, LED10, LED12, LED14, LED16: RED; LED-0603
LOGO1, LOGO3, LOGO5, LOGO7, LOGO9, LOGO11, LOGO13, LOGO15: OSHW-LOGOMINI; OSHW-LOGO-MINI
LOGO2, LOGO4, LOGO6, LOGO8, LOGO10, LOGO12, LOGO14, LOGO16: SFE_LOGO_NAME_FLAME.1_INCH; SFE_LOGO_NAME_FLAME_.1
PPS, PPS1, PPS2, PPS3, PPS4, PPS5, PPS6, PPS7: JUMPER-SMT_2_NC_TRACE_SILK; SMT-JUMPER_2_NC_TRACE_SILK
PWR\, PWR\1, PWR\2, PWR\3, PWR\4, PWR\5, PWR\6, PWR\7: JUMPER-SMT_2_NC_TRACE_SILK; SMT-JUMPER_2_NC_TRACE_SILK
R1, R5, R11, R20, R21, R24, R35, R36, R39, R50, R51, R54, R65, R66, R69, R80, R81, R84, R95, R96, R99, R110, R111, R114: 1k; 0603
R2, R3, R4, R6, R14, R17, R22, R23, R31, R32, R37, R38, R46, R47, R52, R53, R61, R62, R67, R68, R76, R77, R82, R83, R91, R92, R97, R98, R106, R107, R112, R113: 33; 0603
R7, R8, R18, R19, R33, R34, R48, R49, R63, R64, R78, R79, R93, R94, R108, R109: 2.2k; 0603
R9, R10, R25, R26, R40, R41, R55, R56, R70, R71, R85, R86, R100, R101, R115, R116: 27; 0603
R12, R13, R28, R29, R43, R44, R58, R59, R73, R74, R88, R89, R103, R104, R118, R119: 5.1k; 0603
R15, R27, R42, R57, R72, R87, R102, R117: 100k; 0603
R16, R30, R45, R60, R75, R90, R105, R120: 10k; 0402
SPI, SPI1, SPI2, SPI3, SPI4, SPI5, SPI6, SPI7: JUMPER-SMT_2_NO_SILK; SMT-JUMPER_2_NO_SILK
U1, U4, U6, U8, U10, U12, U14, U16: U-BLOX_NEO-M9N; NEO-M9N
U2, U3, U5, U7, U9, U11, U13, U15: 3.3V; SOT23-5
U$1, U$4, U$25, U$28, U$83, U$85, U$124, U$126, U$165, U$167, U$206, U$208, U$247, U$249, U$288, U$290: SDA-[)
U$2, U$76, U$117, U$158, U$199, U$240, U$281, U$322: NEO#M9N1
U$3, U$5, U$27, U$29, U$84, U$86, U$125, U$127, U$166, U$168, U$207, U$209, U$248, U$250, U$289, U$291: SCL-[)
U$6, U$7, U$30, U$32, U$57, U$58, U$60, U$61, U$87, U$88, U$102, U$103, U$128, U$129, U$143, U$144, U$169, U$170, U$184, U$185, U$210, U$211, U$225, U$226, U$251, U$252, U$266, U$267, U$292, U$293, U$307, U$308: 3V3-04
U$8, U$9, U$33, U$42, U$59, U$62, U$63, U$64, U$89, U$90, U$104, U$105, U$130, U$131, U$145, U$146, U$171, U$172, U$186, U$187, U$212, U$213, U$227, U$228, U$253, U$254, U$268, U$269, U$294, U$295, U$309, U$310: GND-04
U$10, U$45, U$91, U$132, U$173, U$214, U$255, U$296: I_SUPER2_C-()-03
U$11, U$77, U$118, U$159, U$200, U$241, U$282, U$323: SPI1
U$12, U$52, U$56, U$79, U$101, U$120, U$142, U$161, U$183, U$202, U$224, U$243, U$265, U$284, U$306, U$325: PPS0
U$13, U$81, U$122, U$163, U$204, U$245, U$286, U$327: ANT0
U$14, U$78, U$119, U$160, U$201, U$242, U$283, U$324: QWIIC_4MM
U$15, U$16, U$46, U$47, U$92, U$93, U$133, U$134, U$174, U$175, U$215, U$216, U$256, U$257, U$297, U$298: INT8
U$17, U$80, U$121, U$162, U$203, U$244, U$285, U$326: PWR1
U$18, U$65, U$106, U$147, U$188, U$229, U$270, U$311: PWR-()-03
U$19, U$20, U$66, U$67, U$107, U$108, U$148, U$149, U$189, U$190, U$230, U$231, U$271, U$272, U$312, U$313: 5V
U$21, U$82, U$123, U$164, U$205, U$246, U$287, U$328: NEO_GPS_BOARD_SILK_FINAL#03#JPG
U$22, U$48, U$94, U$135, U$176, U$217, U$258, U$299: U#BLOX3
U$23, U$24, U$68, U$69, U$109, U$110, U$150, U$151, U$191, U$192, U$232, U$233, U$273, U$274, U$314, U$315: CS#-<]
U$26, U$72, U$113, U$154, U$195, U$236, U$277, U$318: RX#MOSI2
U$31, U$73, U$114, U$155, U$196, U$237, U$278, U$319: RX#MOSI3
U$34, U$74, U$115, U$156, U$197, U$238, U$279, U$320: TX#MISO0
U$35, U$36, U$49, U$50, U$95, U$96, U$136, U$137, U$177, U$178, U$218, U$219, U$259, U$260, U$300, U$301: #RST3
U$37, U$75, U$116, U$157, U$198, U$239, U$280, U$321: TX#MISO1
U$38, U$41, U$70, U$71, U$111, U$112, U$152, U$153, U$193, U$194, U$234, U$235, U$275, U$276, U$316, U$317: SCK-(]-04
U$39, U$40, U$51, U$53, U$97, U$98, U$138, U$139, U$179, U$180, U$220, U$221, U$261, U$262, U$302, U$303: #SAFE1
U$43, U$44, U$54, U$55, U$99, U$100, U$140, U$141, U$181, U$182, U$222, U$223, U$263, U$264, U$304, U$305: PPS5
Y1, Y2, Y3, Y4, Y5, Y6, Y7, Y8: GPS_CHIP_ANTENNAW3011; W3011

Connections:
3.3V: C4.1, C5.2, D2.A, J1.3, J2.2, J4.2, J5.2, JP5.2, PWR\.2, R15.2, R16.2, U1.7, U1.23, U2.5
3.3V1: C2.1, C7.2, D1.A, J6.2, J7.2, J8.3, J9.2, JP6.2, PWR\1.2, R27.2, R30.2, U3.5, U4.7, U4.23
3.3V2: C10.1, C11.2, D5.A, J11.2, J12.2, J13.3, J14.2, JP17.2, PWR\2.2, R42.2, R45.2, U5.5, U6.7, U6.23
3.3V3: C14.1, C15.2, D7.A, J16.2, J17.2, J18.3, J19.2, JP28.2, PWR\3.2, R57.2, R60.2, U7.5, U8.7, U8.23
3.3V4: C18.1, C19.2, D9.A, J21.2, J22.2, J23.3, J24.2, JP39.2, PWR\4.2, R72.2, R75.2, U9.5, U10.7, U10.23
3.3V5: C22.1, C23.2, D11.A, J26.2, J27.2, J28.3, J29.2, JP50.2, PWR\5.2, R87.2, R90.2, U11.5, U12.7, U12.23
3.3V6: C26.1, C27.2, D13.A, J31.2, J32.2, J33.3, J34.2, JP60.2, PWR\6.2, R102.2, R105.2, U13.5, U14.7, U14.23
3.3V7: C30.1, C31.2, D15.A, J36.2, J37.2, J38.3, J39.2, JP72.2, PWR\7.2, R117.2, R120.2, U15.5, U16.7, U16.23
5V: C6.1, D3.5, J1.2, J3.VBUS1, J3.VBUS2, U2.1, U2.3
5V1: C8.1, D4.5, J8.2, J10.VBUS1, J10.VBUS2, U3.1, U3.3
5V2: C12.1, D6.5, J13.2, J15.VBUS1, J15.VBUS2, U5.1, U5.3
5V3: C16.1, D8.5, J18.2, J20.VBUS1, J20.VBUS2, U7.1, U7.3
5V4: C20.1, D10.5, J23.2, J25.VBUS1, J25.VBUS2, U9.1, U9.3
5V5: C24.1, D12.5, J28.2, J30.VBUS1, J30.VBUS2, U11.1, U11.3
5V6: C28.1, D14.5, J33.2, J35.VBUS1, J35.VBUS2, U13.1, U13.3
5V7: C32.1, D16.5, J38.2, J40.VBUS1, J40.VBUS2, U15.1, U15.3
!RESET: JP15.3, U1.8
!RESET1: JP11.3, U4.8
!RESET2: JP23.3, U6.8
!RESET3: JP34.3, U8.8
!RESET4: JP45.3, U10.8
!RESET5: JP55.3, U12.8
!RESET6: JP66.3, U14.8
!RESET7: JP77.3, U16.8
!SAFE: JP15.2, U1.1
!SAFE1: JP11.2, U4.1
!SAFE2: JP23.2, U6.1
!SAFE3: JP34.2, U8.1
!SAFE4: JP45.2, U10.1
!SAFE5: JP55.2, U12.1
!SAFE6: JP66.2, U14.1
!SAFE7: JP77.2, U16.1
BACKUP: B1.+, C3.1, R5.1, U1.22
BACKUP1: B2.+, C1.1, R20.1, U4.22
BACKUP2: B3.+, C9.1, R35.1, U6.22
BACKUP3: B4.+, C13.1, R50.1, U8.22
BACKUP4: B5.+, C17.1, R65.1, U10.22
BACKUP5: B6.+, C21.1, R80.1, U12.22
BACKUP6: B7.+, C25.1, R95.1, U14.22
BACKUP7: B8.+, C29.1, R110.1, U16.22
D+: D3.4, R9.1
D+1: D4.4, R25.1
D+2: D6.4, R40.1
D+3: D8.4, R55.1
D+4: D10.4, R70.1
D+5: D12.4, R85.1
D+6: D14.4, R100.1
D+7: D16.4, R115.1
D-: D3.6, R10.1
D-1: D4.6, R26.1
D-2: D6.6, R41.1
D-3: D8.6, R56.1
D-4: D10.6, R71.1
D-5: D12.6, R86.1
D-6: D14.6, R101.1
D-7: D16.6, R116.1
D_SEL: R16.1, SPI.2, U1.2
D_SEL1: R30.1, SPI1.2, U4.2
D_SEL2: R45.1, SPI2.2, U6.2
D_SEL3: R60.1, SPI3.2, U8.2
D_SEL4: R75.1, SPI4.2, U10.2
D_SEL5: R90.1, SPI5.2, U12.2
D_SEL6: R105.1, SPI6.2, U14.2
D_SEL7: R120.1, SPI7.2, U16.2
GND: B1.-, C3.2, C4.2, C5.1, C6.2, D3.2, J1.1, J2.1, J3.GND, J3.GND2, J4.1, J5.1, LED1.C, LED2.C, R12.1, R13.1, R15.1, SPI.1, U1.10, U1.12, U1.13, U1.24, U2.2, Y1.2, Y1.3
GND1: B2.-, C1.2, C2.2, C7.1, C8.2, D4.2, J6.1, J7.1, J8.1, J9.1, J10.GND, J10.GND2, LED3.C, LED4.C, R27.1, R28.1, R29.1, SPI1.1, U3.2, U4.10, U4.12, U4.13, U4.24, Y2.2, Y2.3
GND2: B3.-, C9.2, C10.2, C11.1, C12.2, D6.2, J11.1, J12.1, J13.1, J14.1, J15.GND, J15.GND2, LED5.C, LED6.C, R42.1, R43.1, R44.1, SPI2.1, U5.2, U6.10, U6.12, U6.13, U6.24, Y3.2, Y3.3
GND3: B4.-, C13.2, C14.2, C15.1, C16.2, D8.2, J16.1, J17.1, J18.1, J19.1, J20.GND, J20.GND2, LED7.C, LED8.C, R57.1, R58.1, R59.1, SPI3.1, U7.2, U8.10, U8.12, U8.13, U8.24, Y4.2, Y4.3
GND4: B5.-, C17.2, C18.2, C19.1, C20.2, D10.2, J21.1, J22.1, J23.1, J24.1, J25.GND, J25.GND2, LED9.C, LED10.C, R72.1, R73.1, R74.1, SPI4.1, U9.2, U10.10, U10.12, U10.13, U10.24, Y5.2, Y5.3
GND5: B6.-, C21.2, C22.2, C23.1, C24.2, D12.2, J26.1, J27.1, J28.1, J29.1, J30.GND, J30.GND2, LED11.C, LED12.C, R87.1, R88.1, R89.1, SPI5.1, U11.2, U12.10, U12.12, U12.13, U12.24, Y6.2, Y6.3
GND6: B7.-, C25.2, C26.2, C27.1, C28.2, D14.2, J31.1, J32.1, J33.1, J34.1, J35.GND, J35.GND2, LED13.C, LED14.C, R102.1, R103.1, R104.1, SPI6.1, U13.2, U14.10, U14.12, U14.13, U14.24, Y7.2, Y7.3
GND7: B8.-, C29.2, C30.2, C31.1, C32.2, D16.2, J36.1, J37.1, J38.1, J39.1, J40.GND, J40.GND2, LED15.C, LED16.C, R117.1, R118.1, R119.1, SPI7.1, U15.2, U16.10, U16.12, U16.13, U16.24, Y8.2, Y8.3
GPS_ANT1: U1.11, Y1.1
GPS_ANT2: U4.11, Y2.1
GPS_ANT3: U6.11, Y3.1
GPS_ANT4: U8.11, Y4.1
GPS_ANT5: U10.11, Y5.1
GPS_ANT6: U12.11, Y6.1
GPS_ANT7: U14.11, Y7.1
GPS_ANT8: U16.11, Y8.1
INT: JP15.1, U1.4
INT1: JP11.1, U4.4
INT2: JP23.1, U6.4
INT3: JP34.1, U8.4
INT4: JP45.1, U10.4
INT5: JP55.1, U12.4
INT6: JP66.1, U14.4
INT7: JP77.1, U16.4
unnamed: PWR\.1, R1.2
unnamed: LED1.A, R11.1
unnamed: JP6.1, R19.2
unnamed: PPS.1, R11.2
unnamed: JP5.1, R8.2
unnamed: D2.C, R5.2
unnamed: J3.B5, R12.2
unnamed: JP5.3, R7.2
unnamed: J3.A5, R13.2
unnamed: LED2.A, R1.1
unnamed: R9.2, U1.6
unnamed: R10.2, U1.5
unnamed: JP6.3, R18.2
unnamed: LED3.A, R21.1
unnamed: PPS1.1, R21.2
unnamed: D1.C, R20.2
unnamed: LED4.A, R24.1
unnamed: R25.2, U4.6
unnamed: R26.2, U4.5
unnamed: PWR\1.1, R24.2
unnamed: J10.B5, R28.2
unnamed: J10.A5, R29.2
unnamed: JP17.1, R34.2
unnamed: JP17.3, R33.2
unnamed: LED5.A, R36.1
unnamed: PPS2.1, R36.2
unnamed: D5.C, R35.2
unnamed: LED6.A, R39.1
unnamed: R40.2, U6.6
unnamed: R41.2, U6.5
unnamed: PWR\2.1, R39.2
unnamed: J15.B5, R43.2
unnamed: J15.A5, R44.2
unnamed: JP28.1, R49.2
unnamed: JP28.3, R48.2
unnamed: LED7.A, R51.1
unnamed: PPS3.1, R51.2
unnamed: D7.C, R50.2
unnamed: LED8.A, R54.1
unnamed: R55.2, U8.6
unnamed: R56.2, U8.5
unnamed: PWR\3.1, R54.2
unnamed: J20.B5, R58.2
unnamed: J20.A5, R59.2
unnamed: JP39.1, R64.2
unnamed: JP39.3, R63.2
unnamed: LED9.A, R66.1
unnamed: PPS4.1, R66.2
unnamed: D9.C, R65.2
unnamed: LED10.A, R69.1
unnamed: R70.2, U10.6
unnamed: R71.2, U10.5
unnamed: PWR\4.1, R69.2
unnamed: J25.B5, R73.2
unnamed: J25.A5, R74.2
unnamed: JP50.1, R79.2
unnamed: JP50.3, R78.2
unnamed: LED11.A, R81.1
unnamed: PPS5.1, R81.2
unnamed: D11.C, R80.2
unnamed: LED12.A, R84.1
unnamed: R85.2, U12.6
unnamed: R86.2, U12.5
unnamed: PWR\5.1, R84.2
unnamed: J30.B5, R88.2
unnamed: J30.A5, R89.2
unnamed: JP60.1, R94.2
unnamed: JP60.3, R93.2
unnamed: LED13.A, R96.1
unnamed: PPS6.1, R96.2
unnamed: D13.C, R95.2
unnamed: LED14.A, R99.1
unnamed: R100.2, U14.6
unnamed: R101.2, U14.5
unnamed: PWR\6.1, R99.2
unnamed: J35.B5, R103.2
unnamed: J35.A5, R104.2
unnamed: JP72.1, R109.2
unnamed: JP72.3, R108.2
unnamed: LED15.A, R111.1
unnamed: PPS7.1, R111.2
unnamed: D15.C, R110.2
unnamed: LED16.A, R114.1
unnamed: R115.2, U16.6
unnamed: R116.2, U16.5
unnamed: PWR\7.1, R114.2
unnamed: J40.B5, R118.2
unnamed: J40.A5, R119.2
PPS: JP15.4, PPS.2, U1.3
PPS1: JP11.4, PPS1.2, U4.3
PPS2: JP23.4, PPS2.2, U6.3
PPS3: JP34.4, PPS3.2, U8.3
PPS4: JP45.4, PPS4.2, U10.3
PPS5: JP55.4, PPS5.2, U12.3
PPS6: JP66.4, PPS6.2, U14.3
PPS7: JP77.4, PPS7.2, U16.3
RXI/MOSI: J1.5, R6.2
RXI/MOSI1: J8.5, R17.2
RXI/MOSI2: J13.5, R32.2
RXI/MOSI3: J18.5, R47.2
RXI/MOSI4: J23.5, R62.2
RXI/MOSI5: J28.5, R77.2
RXI/MOSI6: J33.5, R92.2
RXI/MOSI7: J38.5, R107.2
RXLV: R6.1, U1.21
RXLV1: R17.1, U4.21
RXLV2: R32.1, U6.21
RXLV3: R47.1, U8.21
RXLV4: R62.1, U10.21
RXLV5: R77.1, U12.21
RXLV6: R92.1, U14.21
RXLV7: R107.1, U16.21
SCL/SCK: J1.7, J2.4, J4.4, J5.4, R4.2, R7.1
SCL/SCK1: J6.4, J7.4, J8.7, J9.4, R18.1, R23.2
SCL/SCK2: J11.4, J12.4, J13.7, J14.4, R33.1, R38.2
SCL/SCK3: J16.4, J17.4, J18.7, J19.4, R48.1, R53.2
SCL/SCK4: J21.4, J22.4, J23.7, J24.4, R63.1, R68.2
SCL/SCK5: J26.4, J27.4, J28.7, J29.4, R78.1, R83.2
SCL/SCK6: J31.4, J32.4, J33.7, J34.4, R93.1, R98.2
SCL/SCK7: J36.4, J37.4, J38.7, J39.4, R108.1, R113.2
SCL_LV: R4.1, U1.19
SCL_LV1: R23.1, U4.19
SCL_LV2: R38.1, U6.19
SCL_LV3: R53.1, U8.19
SCL_LV4: R68.1, U10.19
SCL_LV5: R83.1, U12.19
SCL_LV6: R98.1, U14.19
SCL_LV7: R113.1, U16.19
SDA/!CS: J1.4, J2.3, J4.3, J5.3, R2.2, R8.1
SDA/!CS1: J6.3, J7.3, J8.4, J9.3, R19.1, R22.2
SDA/!CS2: J11.3, J12.3, J13.4, J14.3, R34.1, R37.2
SDA/!CS3: J16.3, J17.3, J18.4, J19.3, R49.1, R52.2
SDA/!CS4: J21.3, J22.3, J23.4, J24.3, R64.1, R67.2
SDA/!CS5: J26.3, J27.3, J28.4, J29.3, R79.1, R82.2
SDA/!CS6: J31.3, J32.3, J33.4, J34.3, R94.1, R97.2
SDA/!CS7: J36.3, J37.3, J38.4, J39.3, R109.1, R112.2
SDA_LV: R2.1, U1.18
SDA_LV1: R22.1, U4.18
SDA_LV2: R37.1, U6.18
SDA_LV3: R52.1, U8.18
SDA_LV4: R67.1, U10.18
SDA_LV5: R82.1, U12.18
SDA_LV6: R97.1, U14.18
SDA_LV7: R112.1, U16.18
SHLD: J3.SHLD1, J3.SHLD2, J3.SHLD3, J3.SHLD4, J3.SHLD5, J3.SHLD6, J3.SHLD7, J3.SHLD8
SHLD1: J10.SHLD1, J10.SHLD2, J10.SHLD3, J10.SHLD4, J10.SHLD5, J10.SHLD6, J10.SHLD7, J10.SHLD8
SHLD2: J15.SHLD1, J15.SHLD2, J15.SHLD3, J15.SHLD4, J15.SHLD5, J15.SHLD6, J15.SHLD7, J15.SHLD8
SHLD3: J20.SHLD1, J20.SHLD2, J20.SHLD3, J20.SHLD4, J20.SHLD5, J20.SHLD6, J20.SHLD7, J20.SHLD8
SHLD4: J25.SHLD1, J25.SHLD2, J25.SHLD3, J25.SHLD4, J25.SHLD5, J25.SHLD6, J25.SHLD7, J25.SHLD8
SHLD5: J30.SHLD1, J30.SHLD2, J30.SHLD3, J30.SHLD4, J30.SHLD5, J30.SHLD6, J30.SHLD7, J30.SHLD8
SHLD6: J35.SHLD1, J35.SHLD2, J35.SHLD3, J35.SHLD4, J35.SHLD5, J35.SHLD6, J35.SHLD7, J35.SHLD8
SHLD7: J40.SHLD1, J40.SHLD2, J40.SHLD3, J40.SHLD4, J40.SHLD5, J40.SHLD6, J40.SHLD7, J40.SHLD8
TXLV: R3.1, U1.20
TXLV1: R14.1, U4.20
TXLV2: R31.1, U6.20
TXLV3: R46.1, U8.20
TXLV4: R61.1, U10.20
TXLV5: R76.1, U12.20
TXLV6: R91.1, U14.20
TXLV7: R106.1, U16.20
TXO/MISO: J1.6, R3.2
TXO/MISO1: J8.6, R14.2
TXO/MISO2: J13.6, R31.2
TXO/MISO3: J18.6, R46.2
TXO/MISO4: J23.6, R61.2
TXO/MISO5: J28.6, R76.2
TXO/MISO6: J33.6, R91.2
TXO/MISO7: J38.6, R106.2
USB_D+: D3.3, J3.A6, J3.B6
USB_D+1: D4.3, J10.A6, J10.B6
USB_D+2: D6.3, J15.A6, J15.B6
USB_D+3: D8.3, J20.A6, J20.B6
USB_D+4: D10.3, J25.A6, J25.B6
USB_D+5: D12.3, J30.A6, J30.B6
USB_D+6: D14.3, J35.A6, J35.B6
USB_D+7: D16.3, J40.A6, J40.B6
USB_D-: D3.1, J3.A7, J3.B7
USB_D-1: D4.1, J10.A7, J10.B7
USB_D-2: D6.1, J15.A7, J15.B7
USB_D-3: D8.1, J20.A7, J20.B7
USB_D-4: D10.1, J25.A7, J25.B7
USB_D-5: D12.1, J30.A7, J30.B7
USB_D-6: D14.1, J35.A7, J35.B7
USB_D-7: D16.1, J40.A7, J40.B7

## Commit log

2019-08-27 Adds USB-C connector, removes some stat LEDs, adds power led jumper
    [SparkFun GPS NEO_M9N.brd, SparkFun GPS NEO_M9N.sch]
2019-08-28 Initial issues dealt with, air wires etc
    [SparkFun GPS NEO_M9N.brd]
2019-08-28 Updates the order of the info boxes in the schematic, adds 10k pullup to D_SEL
    [SparkFun GPS NEO_M9N.brd, SparkFun GPS NEO_M9N.sch]
2019-08-28 Routes 10k pullup resistor, adds labels, fixes air wires
    [SparkFun GPS NEO_M9N.brd, SparkFun GPS NEO_M9N.sch]
2019-08-28 Adds gerber files
    [SparkFun GPS NEO_M9N.GBL, SparkFun GPS NEO_M9N.GBO, SparkFun GPS NEO_M9N.GBS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]
2019-09-05 Beings work on version with antenna
    [SparkFun GPS NEO_M9N.brd, SparkFun GPS NEO_M9N.sch, SparkFun GPS NEO_M9N_ANT.brd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]
2019-09-05 Initial design for product with antenna
    [SparkFun GPS NEO_M9N_ANT.brd]
2019-09-05 Fixes small DRC problems, Adds silk to battery, adds production id to NEO-M9N chip
    [SparkFun GPS NEO_M9N.brd, SparkFun GPS NEO_M9N.sch]
2019-09-05 Renames version with u.FL connector to reflect that it is the one with a u.FL
    [SparkFun GPS NEO_M9N_uFL.brd, SparkFun GPS NEO_M9N_uFL.sch]
2019-09-11 Adds coplanar waveguide for antenna to antenna version, adds gerbers for uFL version
    [SparkFun GPS NEO_M9N_ANT.brd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]
2019-09-11 Adds chip antenna documentation
2019-09-12 Changes trace for antenna to s-bend, adds silk to battery, adds vcc range to schematic, adjusts jumper
    [SparkFun GPS NEO_M9N_ANT.brd, SparkFun GPS NEO_M9N_ANT.sch]
2019-09-12 Fixes some DRC error
    [SparkFun GPS NEO_M9N_ANT.brd, SparkFun GPS NEO_M9N_ANT.sch]
2019-09-12 Adds gerbers for NEO-M9N with chip antenna
    [SparkFun GPS NEO_M9N.GBL, SparkFun GPS NEO_M9N.GBO, SparkFun GPS NEO_M9N.GBS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]
2019-09-13 Adds sweet silk to NEO board
    [SparkFun GPS NEO_M9N_uFL.brd, SparkFun GPS NEO_M9N_uFL.sch]
2019-09-13 Adds sweet silk to Antenna design
    [SparkFun GPS NEO_M9N_ANT.brd]
2019-09-16 Updates both designs with 5.1k resistor in 0603 package
    [SparkFun GPS NEO_M9N_ANT.brd, SparkFun GPS NEO_M9N_ANT.sch, SparkFun GPS NEO_M9N_uFL.brd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]
2019-09-17 Updates Antenna silk
    [SparkFun GPS NEO_M9N_uFL.brd]
2019-09-17 Moves little bits around
    [SparkFun GPS NEO_M9N_uFL.brd]
2019-09-17 Fixes 5V line, changes version
    [SparkFun GPS NEO_M9N_uFL.brd]
2019-09-17 Missed version updated
    [SparkFun GPS NEO_M9N_uFL.sch]
2019-10-21 Moves production files around
    [SparkFun GPS NEO_M9N.GBL, SparkFun GPS NEO_M9N.GBO, SparkFun GPS NEO_M9N.GBS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]
2019-10-21 Updates the antenna version to have better ground pour on the antenna, and a better curve on the feed line
    [SparkFun GPS NEO_M9N_ANT.brd]
2019-10-21 Changes version to v02
    [SparkFun GPS NEO_M9N_ANT.brd, SparkFun GPS NEO_M9N_ANT.sch]
2019-10-21 Creates prototype version without Qwiic connector near gps antenna
    [SparkFun GPS NEO_M9N_ANT_PROTO2.brd, SparkFun GPS NEO_M9N_ANT_PROTO2.sch]
2019-10-21 Changes version on single-qwiic board to v03
    [SparkFun GPS NEO_M9N_ANT_PROTO2.sch]
2019-10-21 ....and now renames board files to proto3 to align with v03 copper and schematic text
    [SparkFun GPS NEO_M9N_ANT_PROTO3.brd, SparkFun GPS NEO_M9N_ANT_PROTO3.sch]
2019-11-06 Removes VCC bias to antenna from antenna design
    * Deletes all gerber files related to prototypes
    * Moves GPS library out of the buzzard label folder
    * Deletes buzzard labels
    [SparkFun GPS NEO_M9N_ANT.GBL, SparkFun GPS NEO_M9N_ANT.GBO, SparkFun GPS NEO_M9N_ANT.GBS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]
2019-11-07 Updates Schematic to be more neat
    [SparkFun GPS NEO_M9N_ANT.brd, SparkFun GPS NEO_M9N_ANT.sch]
2019-11-07 Moves cap by regulator ever so slightly to get cream from module out of keepout
    [SparkFun GPS NEO_M9N_ANT.brd]
2019-11-07 Moves left qwiic connector down to match right one, updates measures, moves some vias
    [SparkFun GPS NEO_M9N_ANT.brd, SparkFun GPS NEO_M9N_ANT.sch]
2019-11-07 Fixes an air wire and wire stub
    [SparkFun GPS NEO_M9N_ANT.brd]
2019-11-07 Adds production panel gerbers
    [SparkFun GPS NEO_M9N_ANT-Panel.GBL, SparkFun GPS NEO_M9N_ANT-Panel.GBO, SparkFun GPS NEO_M9N_ANT-Panel.GBS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]
2020-01-03 Removes local eagle library and replaces part from that library with part from SparkFun Eagle Library
    [SparkFun GPS NEO_M9N_ANT.brd, SparkFun GPS NEO_M9N_ANT.sch, SparkFun GPS NEO_M9N_uFL.brd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]
2020-09-30 Updates libs, adds SMA connector and rf bias circuit
    [SparkFun GPS NEO_M9N_ANT.brd, SparkFun GPS NEO_M9N_ANT.sch, SparkFun GPS NEO_M9N_uFL.brd]
2020-09-30 Routed updates USB footprint and SMA connector with its RF circuitry
    [SparkFun GPS NEO_M9N_ANT.brd, SparkFun GPS NEO_M9N_ANT.sch]
2020-10-01 Restore chip antenna version, and moves SMA version to its' own folder
    [SparkFun GPS NEO_M9N_SMA.brd, SparkFun GPS NEO_M9N_SMA.sch]
2020-10-01 Adds Silk to "LONG" SMA version, adds measures
    [SparkFun GPS NEO_M9N_SMA _LONG.brd, SparkFun GPS NEO_M9N_SMA _LONG.sch, SparkFun GPS NEO_M9N_SMA.brd]
2020-10-08 Updates SMD, SMA connector with new footprint
    * Fixes connector label in schematic
    * Fixes LED labels
    * Fixes TX/SDO label
    * Adds VCC Range to regulator
    [SparkFun GPS NEO_M9N_SMA _LONG.brd, SparkFun GPS NEO_M9N_SMA _LONG.sch]
2020-10-12 Updates the SMD, SMA Connector with new footprint
    [SparkFun GPS NEO_M9N_SMA _LONG.brd, SparkFun GPS NEO_M9N_SMA _LONG.sch]
2020-10-13 Adds some text for L1/L2 band support on the schematic
    [SparkFun GPS NEO_M9N_SMA _LONG.sch]
2020-10-15 Replaces 1x4 connectors with versions that don't have a SKU
    [SparkFun GPS NEO_M9N_SMA _LONG.brd, SparkFun GPS NEO_M9N_SMA _LONG.sch]
2020-10-15 Removes unused SMA version
    [SparkFun GPS NEO_M9N_SMA.brd, SparkFun GPS NEO_M9N_SMA.sch]
2020-10-15 Changes the "Long" version name to just "SMA"
    [SparkFun GPS NEO_M9N_SMA.brd, SparkFun GPS NEO_M9N_SMA.sch]
2020-10-15 Changes to female SMD, SMA connector
    [SparkFun GPS NEO_M9N_SMA.brd, SparkFun GPS NEO_M9N_SMA.sch]
2020-10-20 v10 panel
    [SparkFun GPS NEO_M9N_SMA-Panel.GBL, SparkFun GPS NEO_M9N_SMA-Panel.GBO, SparkFun GPS NEO_M9N_SMA-Panel.GBP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]
2020-10-21 Moves SMA production files to main production folder
    [SparkFun GPS NEO_M9N_SMA-Panel.GBL, SparkFun GPS NEO_M9N_SMA-Panel.GBO, SparkFun GPS NEO_M9N_SMA-Panel.GBP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]
2022-04-07 Fixes "u-blox" typos in schematic
    [SparkFun GPS NEO_M9N_ANT.sch, SparkFun GPS NEO_M9N_SMA.sch, SparkFun GPS NEO_M9N_uFL.sch]

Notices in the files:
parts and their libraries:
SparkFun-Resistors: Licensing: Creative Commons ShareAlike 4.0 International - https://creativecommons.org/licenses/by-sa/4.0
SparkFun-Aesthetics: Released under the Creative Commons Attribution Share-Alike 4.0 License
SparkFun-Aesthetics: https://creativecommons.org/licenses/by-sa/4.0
